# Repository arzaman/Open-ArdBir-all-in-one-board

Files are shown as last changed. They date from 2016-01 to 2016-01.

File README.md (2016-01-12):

# Open-ArdBir-all-in-one-board
Repository for HW design file (PCB, schematic)  of ArdBir all-in-one board

Open Ardbir is an open source SW (up to release 2.8.3) to control and automate beer brewing process
The SW have been developed based on Arduino UNO board (Atmega328 MCU) with few surroundings HW component to drive and interface external elements (PUMP, Heating element , LCD, push button etc.)

There are few open source HW board available supporting the SW either designed as  shield on top of Arduino Board, in this repository you can find all the CAD design file in order to build an "all-in-one" board that supports microcontroller Atmega328 (Arduino UNO) , all the surrounding componets (power, quartz, USB..) and the specific HW for interfacing brewing elements

The final result will be like this

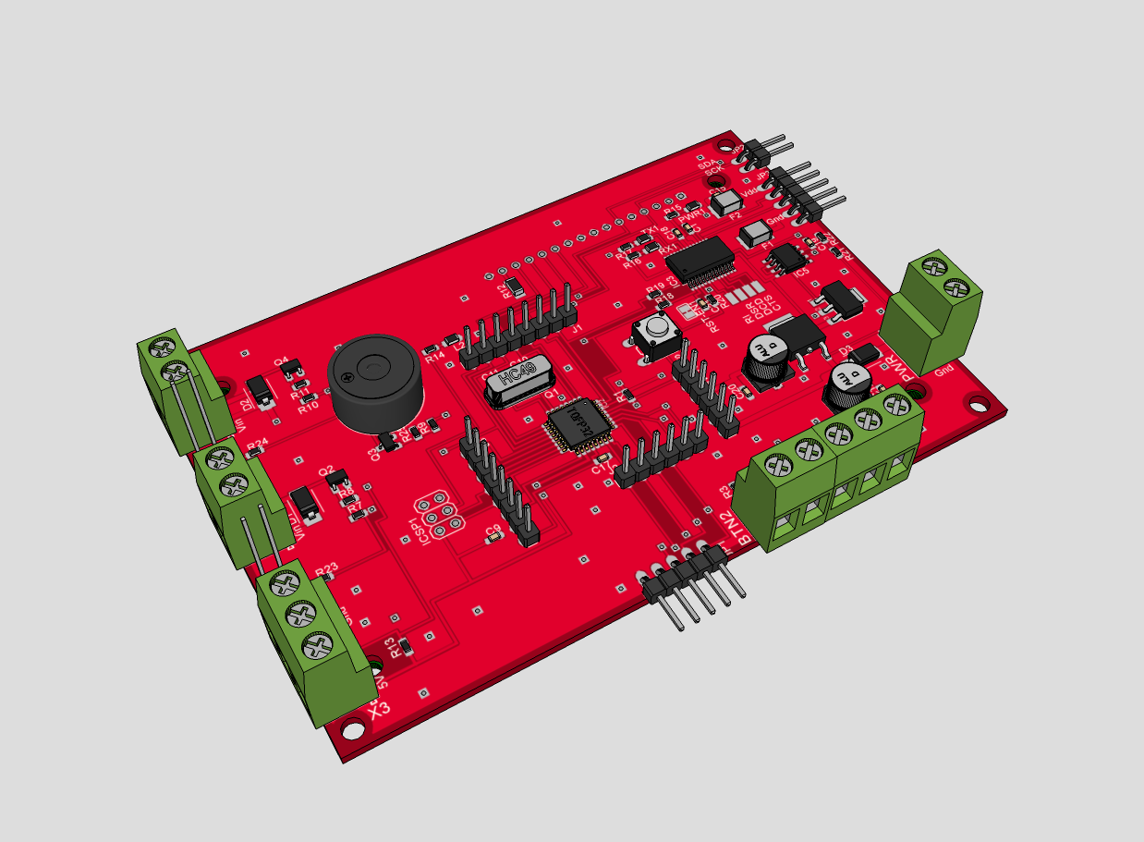
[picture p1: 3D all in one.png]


PCB design

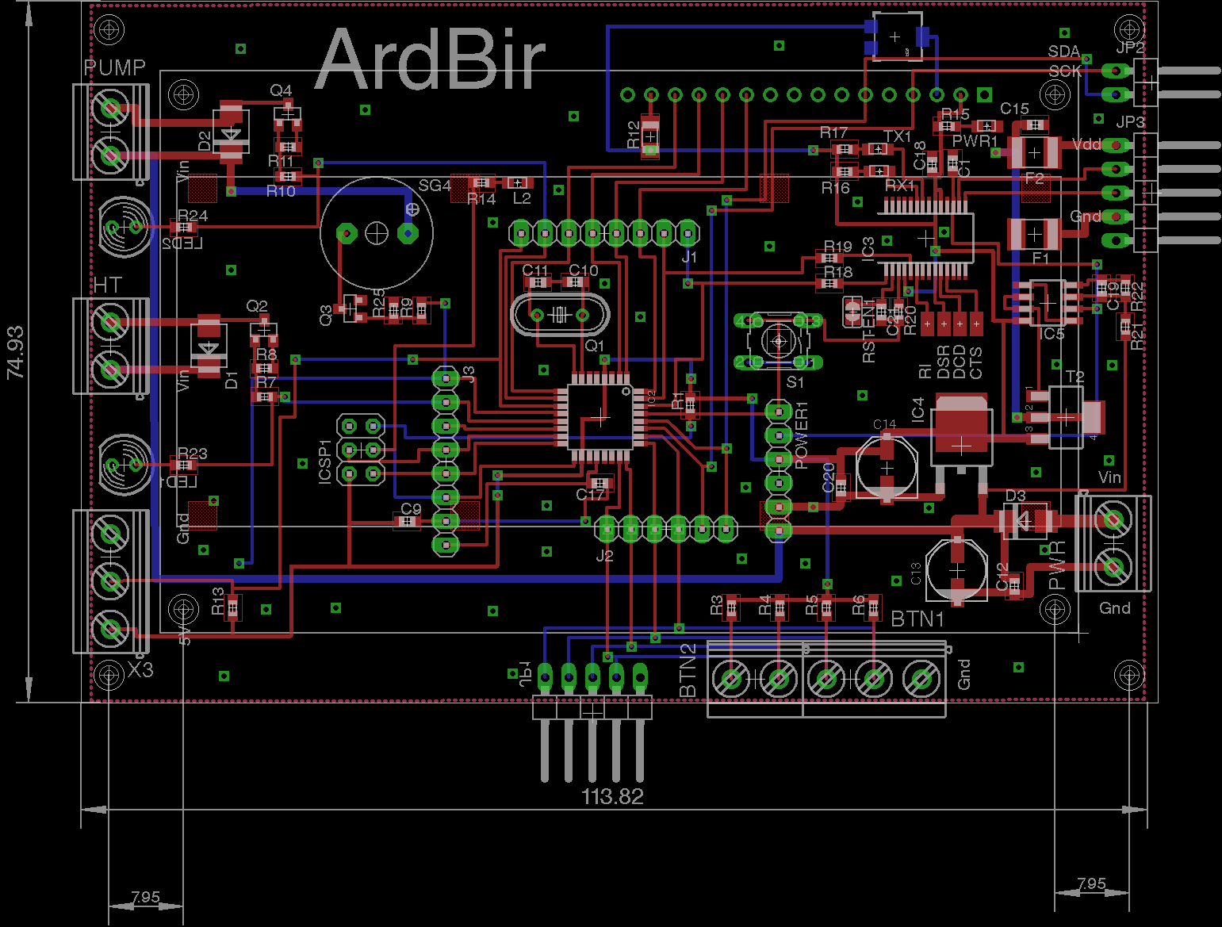
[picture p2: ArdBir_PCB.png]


Schema

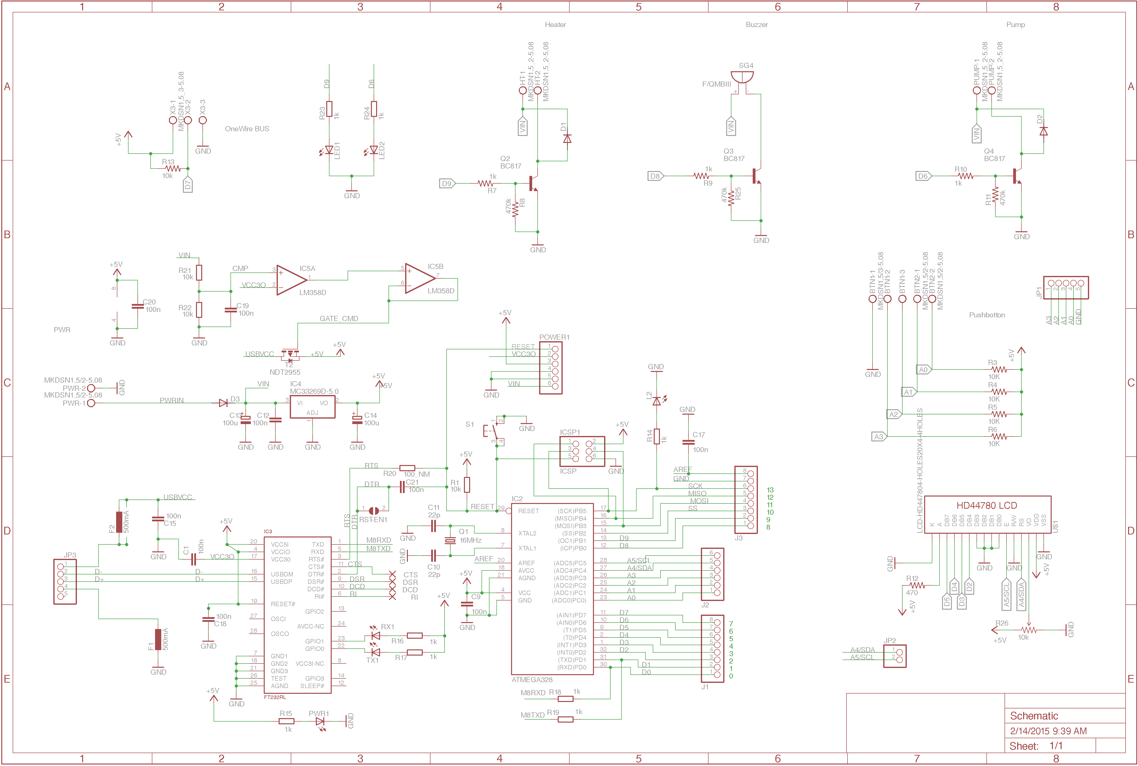
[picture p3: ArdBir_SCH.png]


Enjoy and feel free to use and fork the project

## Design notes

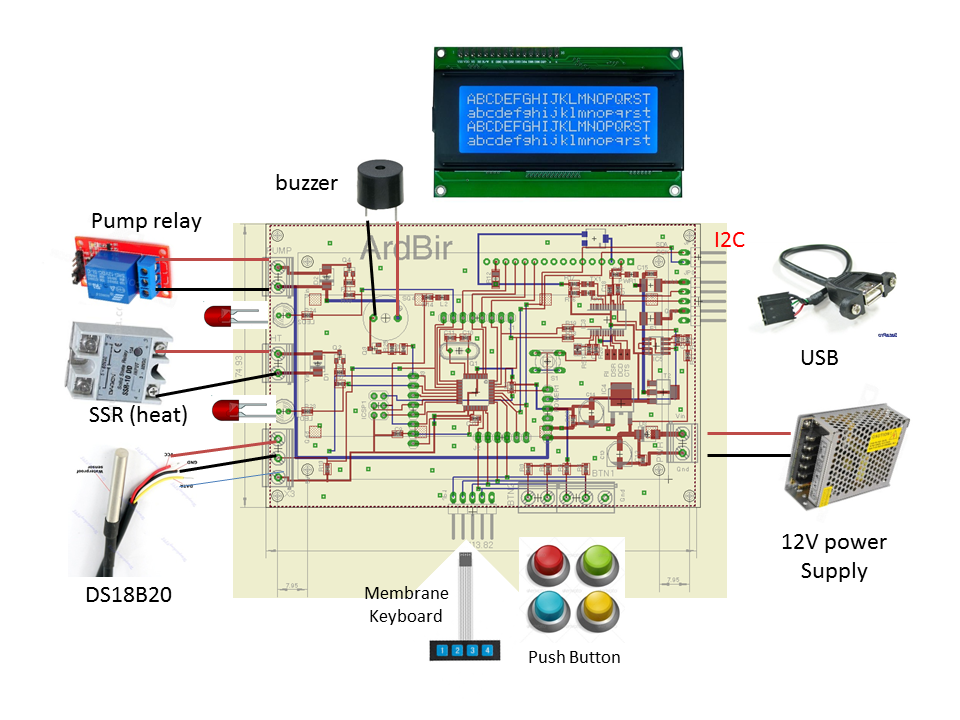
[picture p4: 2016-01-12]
ArdBir Schema all in one.png

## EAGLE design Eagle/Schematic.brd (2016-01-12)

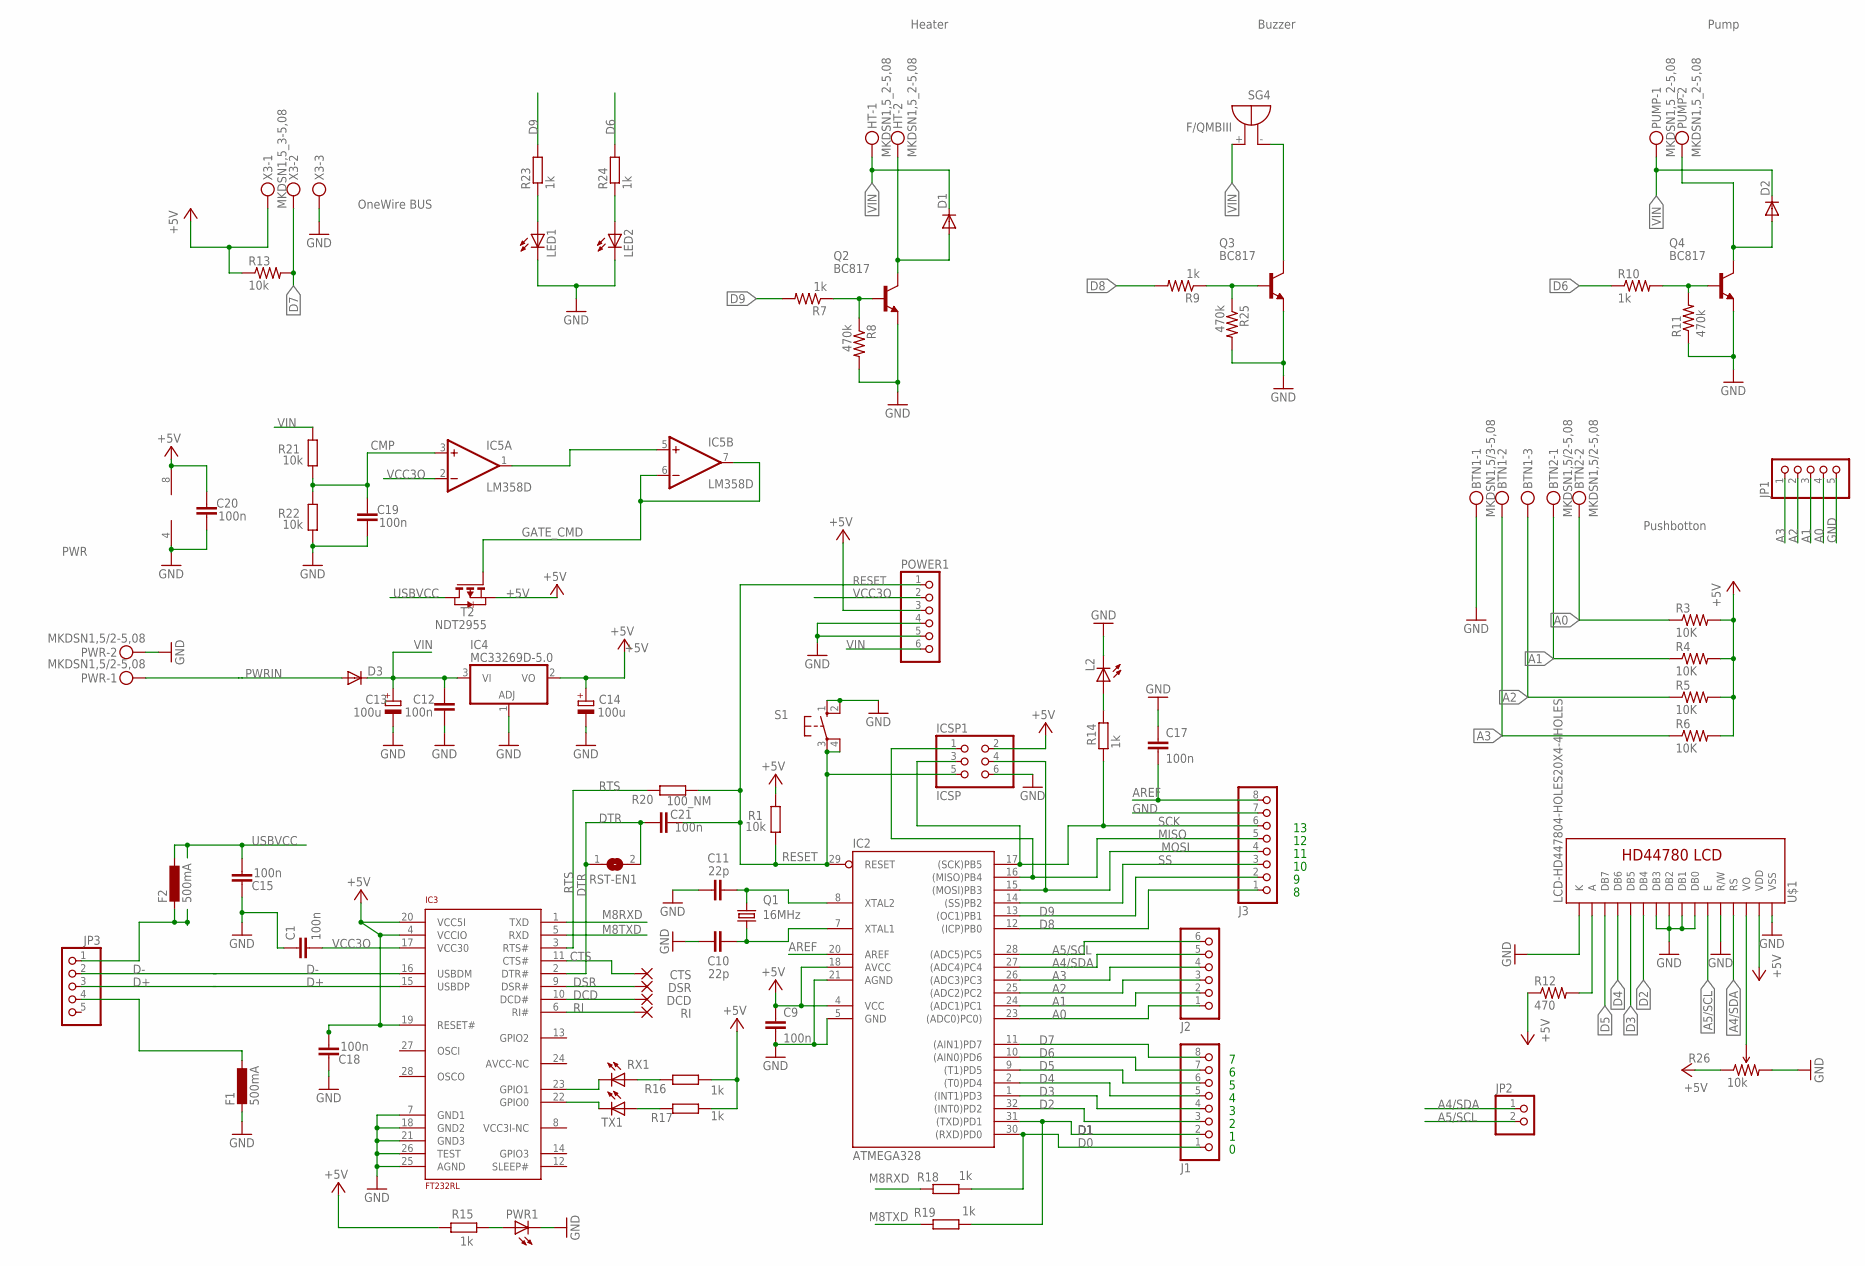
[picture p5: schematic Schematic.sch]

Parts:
BTN1: MKDSN1,5/3-5,08
BTN2: MKDSN1,5/2-5,08
C1, C9, C12, C15, C17, C18, C19, C20, C21: 100n; C0603
C10, C11: 22p; C0603
C13, C14: 100u; PANASONIC_D
CTS: SMD2; SMD1,27-2,54
D1, D2, D3: DIODE-SMB; SMB
DCD: SMD2; SMD1,27-2,54
DSR: SMD2; SMD1,27-2,54
F1, F2: 500mA; L1812
HT: MKDSN1,5_2-5,08; MKDSN1,5-2-5,08
IC2: ATMEGA328; TQFP32-08
IC3: FT232RL; SSOP28
IC4: MC33269D-5.0; DPACK
IC5: LM358D; SO08
ICSP1: ICSP; 2X03
J1, J3: PINHD-1X8; 1X08
J2: PINHD-1X6; 1X06
JP1, JP3: PINHD-1X5/90; 1X05/90
JP2: PINHD-1X2/90; 1X02/90
L2: LEDSML0805; SML0805
LED1, LED2: LED5MM
POWER1: PINHD-1X6; 1X06
PUMP: MKDSN1,5_2-5,08; MKDSN1,5-2-5,08
PWR: MKDSN1,5/2-5,08
PWR1: LEDSML0805; SML0805
Q1: 16MHz; HC49/S
Q2, Q3, Q4: BC817; SOT23-BEC
R1, R13, R21, R22: 10k; R0603
R3, R4, R5, R6: 10K; R0603
R7, R9, R10, R14, R15, R16, R17, R18, R19, R23, R24: 1k; R0603
R8, R11, R25: 470k; R0603
R12: 470; R1206
R20: 100_NM; R0603
R26: 10k; TRIMPOT-5MM
RI: SMD2; SMD1,27-2,54
RST-EN1: SJ
RX1: LEDSML0805; SML0805
S1: 10-XX; B3F-10XX
SG4: F/QMBIII
T2: NDT2955; SOT223
TX1: LEDSML0805; SML0805
U$1: LCD-HD447804-HOLES20X4-4HOLES; LCD-20X4-4HOLES
X3: MKDSN1,5_3-5,08; MKDSN1,5-3-5,08

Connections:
+5V: C9.1, C14.+, C18.1, C20.2, IC2.4 (VCC), IC2.18 (AVCC), IC3.4 (VCCIO), IC3.19 (RESET#), IC3.20 (VCC5I), IC4.2 (VO), IC5.8 (V+), ICSP1.2, POWER1.3, R1.2, R3.2, R4.2, R5.2, R6.2, R12.1, R13.1, R15.1, R16.2, R17.2, R26.A (CCW), T2.3 (S), U$1.P$2 (VDD), X3.1
A0: BTN2.2, IC2.23 ((ADC0)PC0)), J2.1, JP1.4, R3.1
A1: BTN2.1, IC2.24 ((ADC1)PC1), J2.2, JP1.3, R4.1
A2: BTN1.3, IC2.25 ((ADC2)PC2), J2.3, JP1.2, R5.1
A3: BTN1.2, IC2.26 ((ADC3)PC3), J2.4, JP1.1, R6.1
A4/SDA: IC2.27 ((ADC4)PC4), J2.5, JP2.1, U$1.P$4 (RS)
A5/SCL: IC2.28 ((ADC5)PC5), J2.6, JP2.2, U$1.P$6 (E)
AREF: C17.2, IC2.20 (AREF), J3.8
CMP: C19.2, IC5.3 (+IN), R21.1, R22.2
CTS: CTS.1, IC3.11 (CTS#)
D0: IC2.30 ((RXD)PD0), J1.1, R18.1
D1: IC2.31 ((TXD)PD1), J1.2, R19.1
D2: IC2.32 ((INT0)PD2), J1.3, U$1.P$11 (DB4)
D3: IC2.1 ((INT1)PD3), J1.4, U$1.P$12 (DB5)
D4: IC2.2 ((T0)PD4), J1.5, U$1.P$13 (DB6)
D5: IC2.9 ((T1)PD5), J1.6, U$1.P$14 (DB7)
D6: IC2.10 ((AIN0)PD6), J1.7, R10.1, R24.2
D7: IC2.11 ((AIN1)PD7), J1.8, R13.2, X3.2
D8: IC2.12 ((ICP)PB0), J3.1, R9.2
D9: IC2.13 ((OC1)PB1), J3.2, R7.2, R23.2
D+: IC3.15 (USBDP), JP3.3
D-: IC3.16 (USBDM), JP3.2
DCD: DCD.1, IC3.10 (DCD#)
DSR: DSR.1, IC3.9 (DSR#)
DTR: C21.1, IC3.2 (DTR#), RST-EN1.1, RST-EN1.2
GATE_CMD: IC5.6 (-IN), IC5.7 (OUT), T2.1 (G)
GND: BTN1.1, C1.1, C9.2, C10.1, C11.1, C12.1, C13.-, C14.-, C15.2, C17.1, C18.2, C19.1, C20.1, F1.2, IC2.5 (GND), IC2.21 (AGND), IC3.7 (GND1), IC3.18 (GND2), IC3.21 (GND3), IC3.25 (AGND), IC3.26 (TEST), IC4.1 (ADJ), IC5.4 (V-), ICSP1.6, J3.7, JP1.5, L2.C, LED1.K (C), LED2.K (C), POWER1.4, POWER1.5, PWR.2, PWR1.C, Q2.E, Q3.E, Q4.E, R8.2, R11.1, R22.1, R25.2, R26.C (CW), S1.1 (S), S1.2 (S1), U$1.P$1 (VSS), U$1.P$5 (R/W), U$1.P$7 (DB0), U$1.P$8 (DB1), U$1.P$9 (DB2), U$1.P$10 (DB3), U$1.P$16 (K), X3.3
M8RXD: IC3.1 (TXD), R18.2
M8TXD: IC3.5 (RXD), R19.2
MISO: IC2.16 ((MISO)PB4), ICSP1.1, J3.5
MOSI: IC2.15 ((MOSI)PB3), ICSP1.4, J3.4
unnamed: F1.1, JP3.4
unnamed: D1.A, HT.2, Q2.C
unnamed: Q2.B, R7.1, R8.1
unnamed: D2.A, PUMP.2, Q4.C
unnamed: Q3.C, SG4.- (+)
unnamed: Q3.B, R9.1, R25.1
unnamed: Q4.B, R10.2, R11.2
unnamed: R12.2, U$1.P$15 (A)
unnamed: R26.B (WIPER), U$1.P$3 (VO)
unnamed: LED1.A, R23.1
unnamed: LED2.A, R24.1
unnamed: C10.2, IC2.7 (XTAL1), Q1.1
unnamed: C11.2, IC2.8 (XTAL2), Q1.2
unnamed: PWR1.A, R15.2
unnamed: IC3.23 (GPIO1), RX1.C
unnamed: IC3.22 (GPIO0), TX1.C
unnamed: R16.1, RX1.A
unnamed: R17.1, TX1.A
unnamed: F2.2, JP3.1
unnamed: L2.A, R14.1
unnamed: IC5.1 (OUT), IC5.5 (+IN)
PWRIN: D3.A, PWR.1
RESET: C21.2, IC2.29 (RESET), ICSP1.5, POWER1.1, R1.1, R20.2, S1.3, S1.4 (P1)
RI: IC3.6 (RI#), RI.1
RTS: IC3.3 (RTS#), R20.1
SCK: IC2.17 ((SCK)PB5), ICSP1.3, J3.6, R14.2
SS: IC2.14 ((SS)PB2), J3.3
USBVCC: C15.1, F2.1, T2.2 (D), T2.4 (D)
VCC3O: C1.2, IC3.17 (VCC30), IC5.2 (-IN), POWER1.2
VIN: C12.2, C13.+, D1.C, D2.C, D3.C, HT.1, IC4.3 (VI), POWER1.6, PUMP.1, R21.2, SG4.+ (-)

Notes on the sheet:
Pushbotton
Heater
Buzzer
Pump
PWR
OneWire BUS

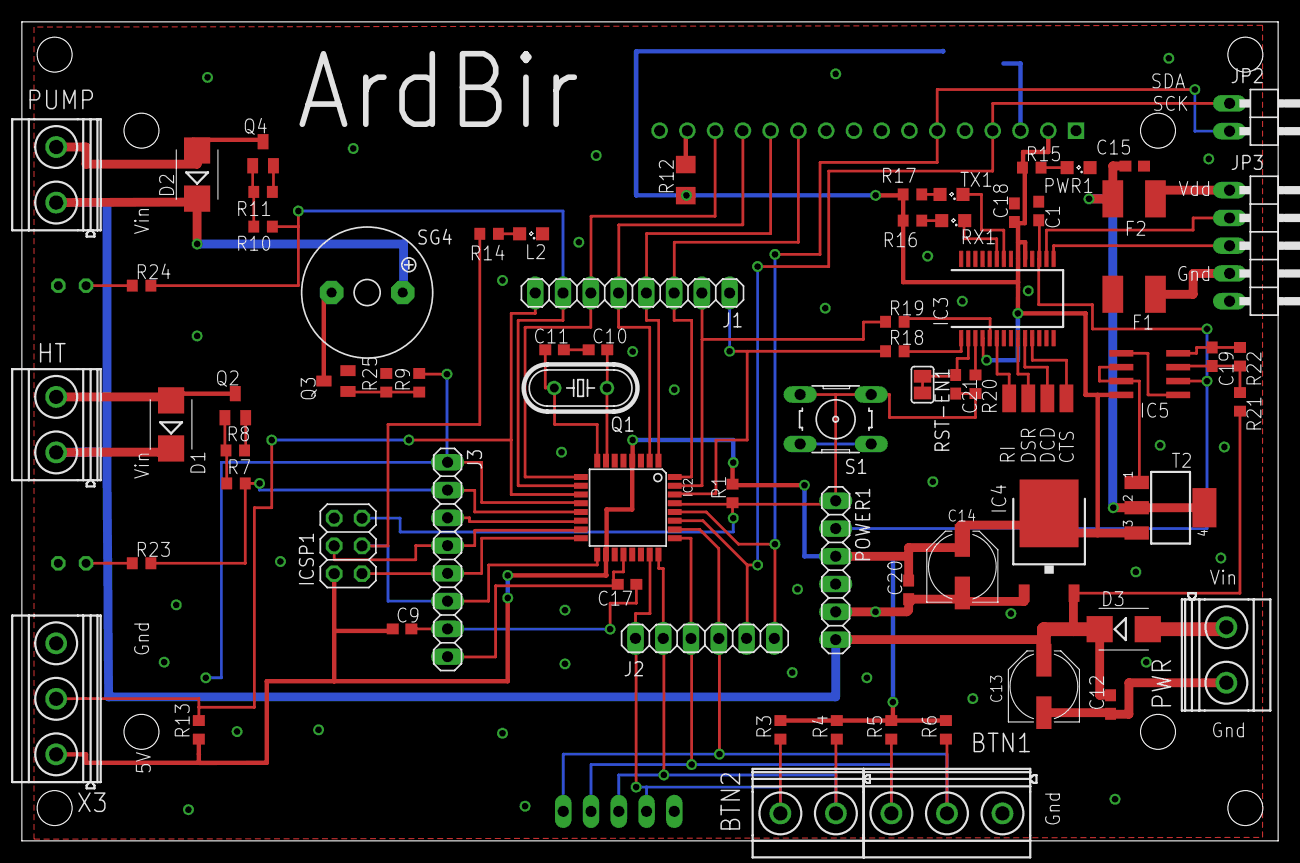
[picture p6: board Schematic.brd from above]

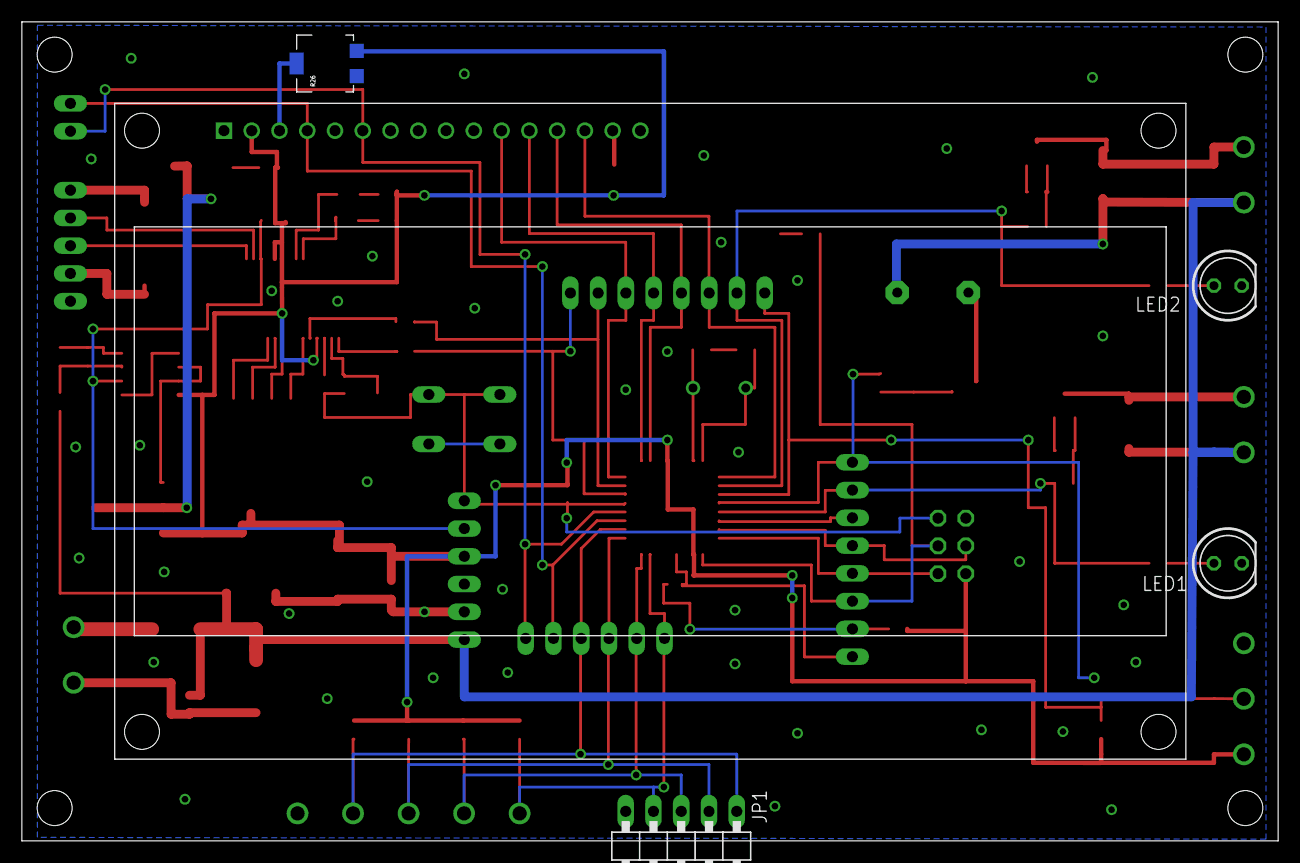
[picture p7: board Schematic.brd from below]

Board: 2 copper layers, 114.9 x 74.9 mm, 80 parts (5 on the bottom side), 61 nets.

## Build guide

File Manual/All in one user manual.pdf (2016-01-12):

## Open ArdBir Connection diagram and integration manual

Thank you for supporting Open Ardbir project , in the following pages are collected all the info to set up your all in one board.

USB Driver Installation

Board comes with pre-installed Arduino UNO boot loader and last ArdBir SW version. In case you need to install new SW version or your own code customization you can mange trough USB board and Arduino IDE. The board is detected as Arduino UNO but you need to install driver fro FT232 UART converter.

The drive can be downloaded from the official page

http://www.ftdichip.com/Drivers/VCP.htm

download and install the one for your operating system

Once installed plug the USB cable and a virtual com port is created , select that port in the Arduino IDE

Boot and SW configuration

All in one board is pre-loaded with last SW version and is ready to go !

BEFORE any operation please remember to run a COMPLETE set up of the PID-PWM configuration and unit parameter configuration

All details are reported in the user manual

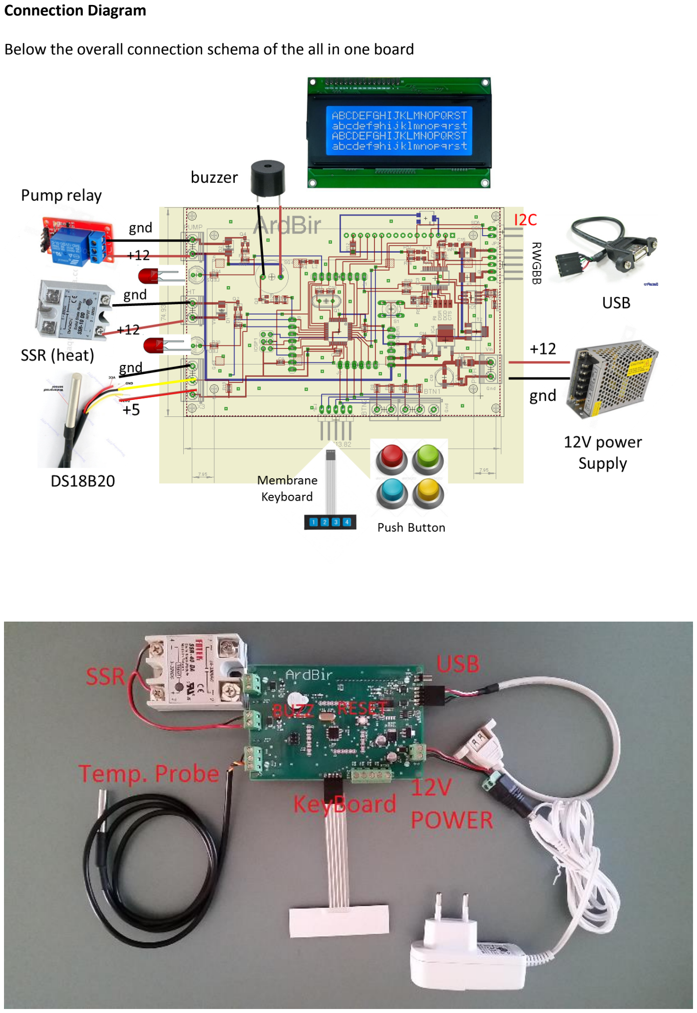
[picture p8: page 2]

Connection Diagram

Below the overall connection schema of the all in one board

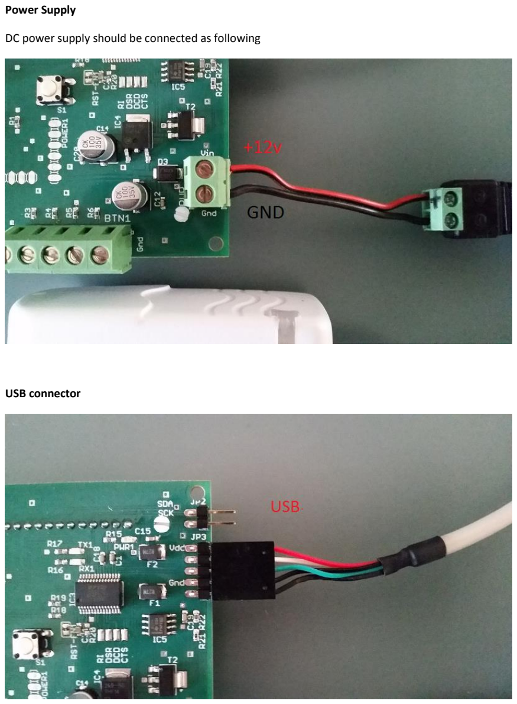
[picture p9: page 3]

Power Supply

DC power supply should be connected as following

USB connector

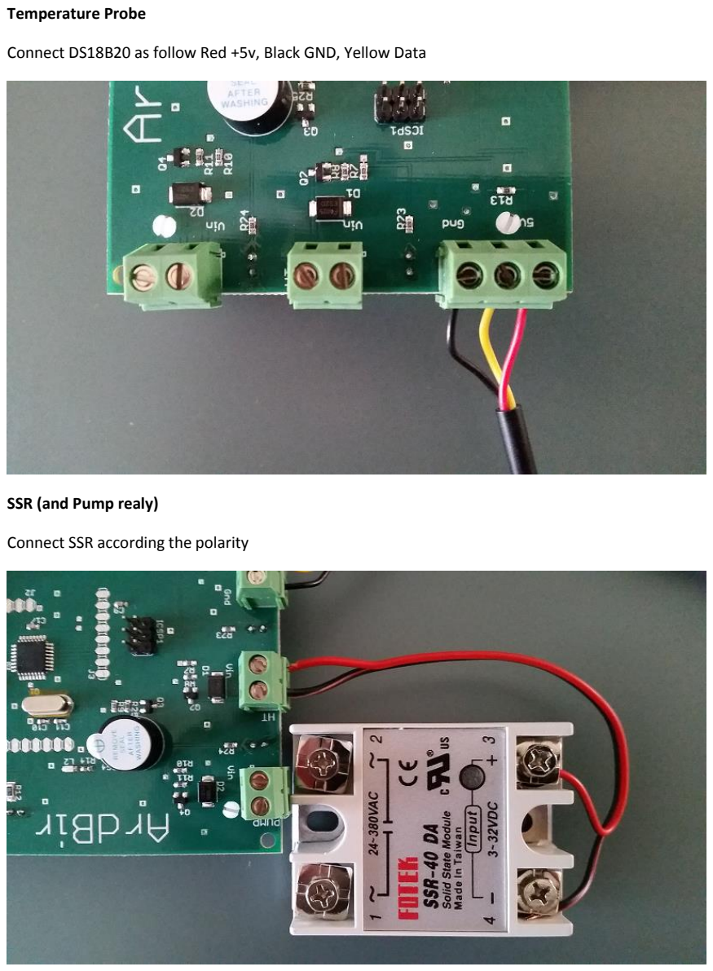
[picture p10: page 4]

Temperature Probe

Connect DS18B20 as follow Red +5v, Black GND, Yellow Data

SSR (and Pump realy)

Connect SSR according the polarity

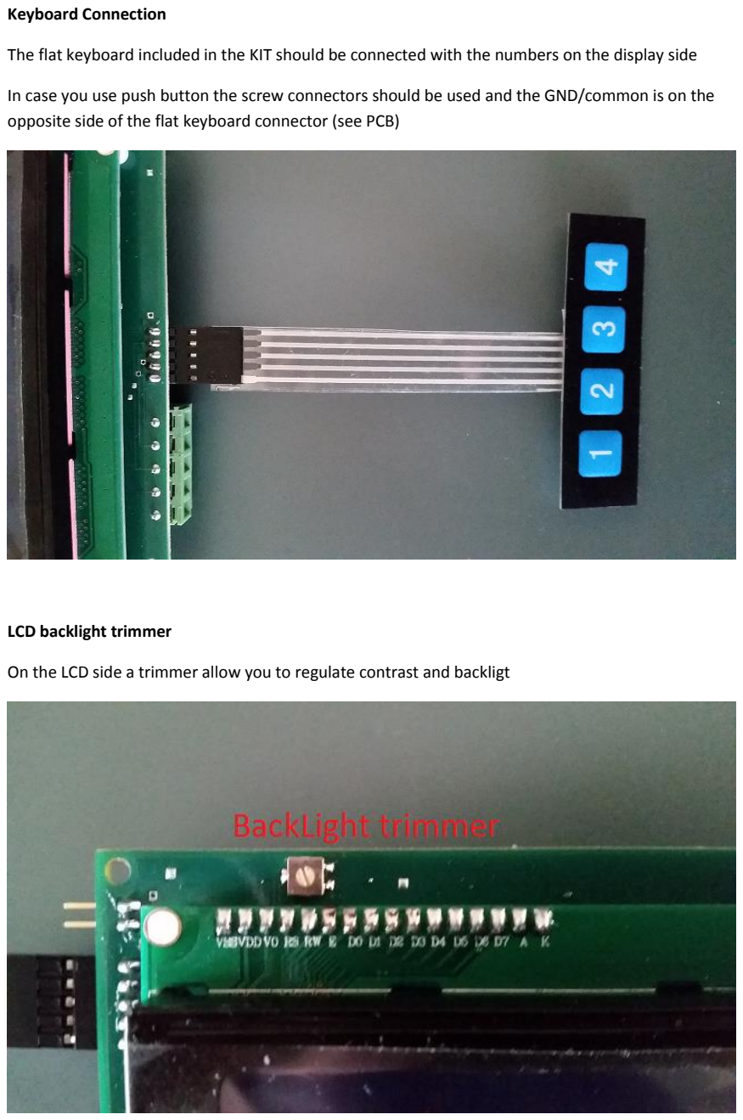
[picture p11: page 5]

Keyboard Connection

The flat keyboard included in the KIT should be connected with the numbers on the display side

In case you use push button the screw connectors should be used and the GND/common is on the opposite side of the flat keyboard connector (see PCB)

LCD backlight trimmer

On the LCD side a trimmer allow you to regulate contrast and backligt

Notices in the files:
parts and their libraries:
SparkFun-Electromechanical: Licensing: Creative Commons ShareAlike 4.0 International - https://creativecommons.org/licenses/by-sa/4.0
